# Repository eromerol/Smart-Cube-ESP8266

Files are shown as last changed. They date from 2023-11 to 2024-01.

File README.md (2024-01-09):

# Smart-Cube-ESP8266



DIY version of the **Aqara Magic Cube** with ESP8266.

This project is part of the Industrial Informatics course of the Electronics, Robotics and Mechatronics Engineering degree at the University of Malaga. 

The working group is formed by:
- Herrero Sánchez, María
- Romero Luque, Elisabeth María
- Serra González, Bartomeu

The project is inspired by: https://www.youtube.com/watch?v=N68S9l9z9i8
and following the tutorial of: https://naylampmechatronics.com/blog/45_tutorial-mpu6050-acelerometro-y-giroscopio.html

The descriptions of the elements used, together with their connection and description can be found at: 
* [Spanish version](https://github.com/eromerol/Smart-Cube-ESP8266/blob/main/Spanish%20Version/Montaje.md)
* [English version](https://github.com/eromerol/Smart-Cube-ESP8266/blob/main/English%20Version/Assembly.md)

The process of programming and commissioning of the cube can be found at: (insert link)

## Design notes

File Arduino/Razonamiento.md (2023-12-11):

# Desarrollo del '*programa_definitivo.ino*'

En este documento se detalla el funcionamiento del programa de Arduino.

Son necesarias las **librerías**:
  - Wire.h
  - MPU6050.h
  - I2Cdev.h

## SetUp

El SetUp tiene la forma:
<p align="center">


Donde se inicializa el sensor MPU6050 y se asigna el pin 16 (Vibration_signal) del sensor de vibración como entrada.

## Loop

Una vez dentro del bucle principal, obtenemos las lecturas de la rotación y de la aceleración:
<p align="center">


Y se le asignan a las variables creadas previamente:

<p align="center">


**NOTA:** Si vamos al [repositorio de la biblioteca MPU6050](https://github.com/ElectronicCats/mpu6050), dentro de 'src' encontramos la deifinición de los procedimientos en la carpeta MPU6050.cpp:

- **getRotation**
<p align="center">


- **getAcceleration**
<p align="center">


Donde se lee que las lecturas son de tipo entero de 16 bits y están en formato complemento a 2, por lo que después se les hace la conversión al sistema internacional.

**NOTA:** los rangos con los que está configurado el MPU6050 pueden ser 2g/4g/8g/16g para el acelerómetro y 250/500/1000/2000(°/s) para el giroscopio. Trabajaremos con los rangos por defecto (2g y 250°/s). La resolución de las lecturas es de 16 bits, por lo que el rango de lectura es de -32768 a 32767.

Sabiendo estos datos, la conversión para la lectura del giroscópio y la del acelerómetro queda como se muestra:

<p align="center">


## Cálculos de las rotaciones y las aceleraciones

Para calcular el ángulo actual necesitamos integrar la velocidad y conocer el ángulo incial. Esto lo hacemos usando la siguiente formula:

<p align="center">




Por lo que se declara: *(no sé por qué lo divide por 131)*

<p align="center">


---

Se calcula la **inclinación en cada eje** con la siguiente conversión.
La única fuerza que actúa sobre el sensor es la fuerza de la **gravedad**, por lo que los valores que obtenemos en las componentes del acelerómetro corresponden a la gravedad.

<p align="center">


De donde se puede deducir:

<p align="center">


Obteniendo los ángulos de inclinación:

<p align="center">


[EJEMPLO GET TEMPERATURE](https://www.i2cdevlib.com/forums/topic/612-why-the-3653-degree-offset-to-get-temperature/)
https://www.i2cdevlib.com/forums/topic/612-why-the-3653-degree-offset-to-get-temperature/

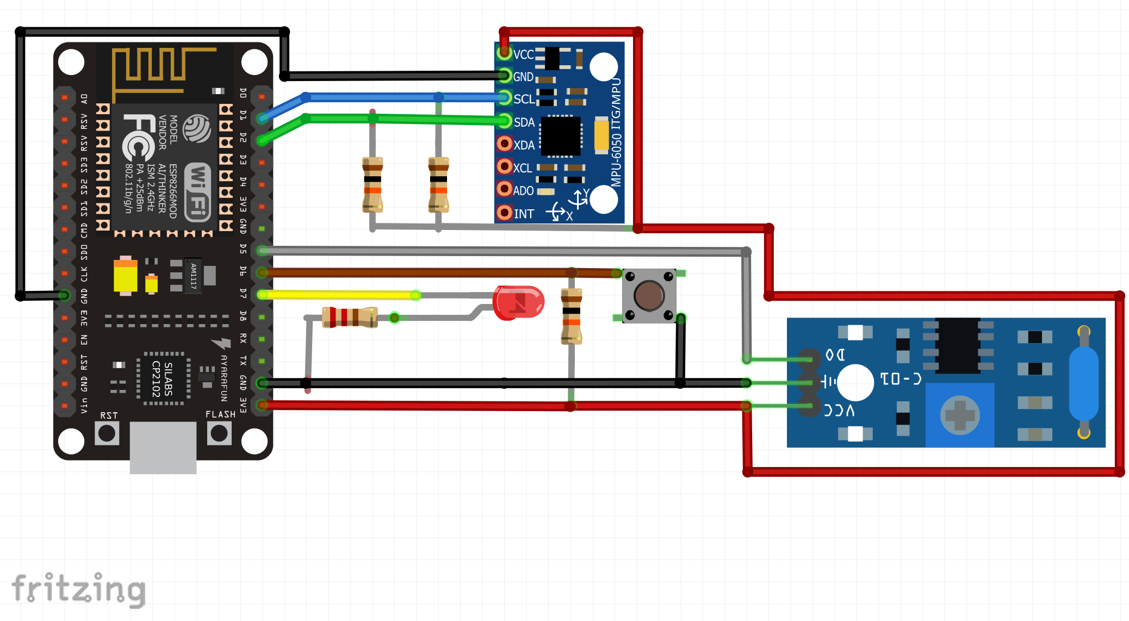
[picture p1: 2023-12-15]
Fritzing/Completo.png

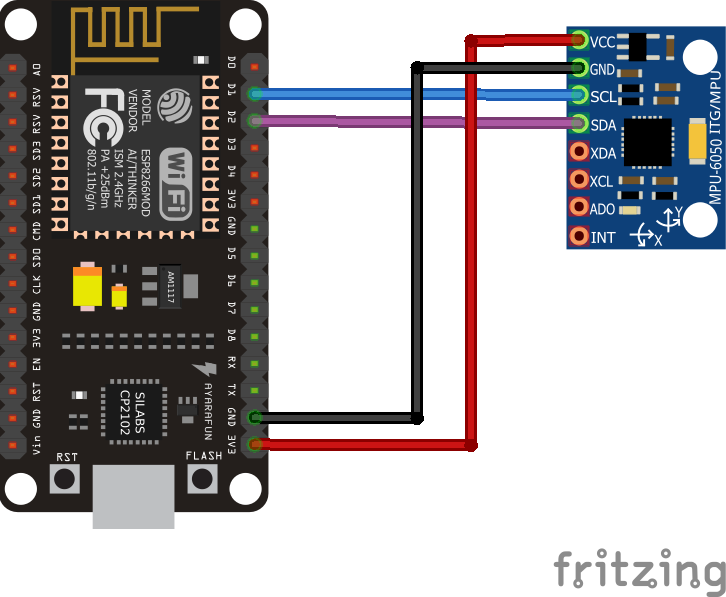
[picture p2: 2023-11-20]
Fritzing/conexion_esp8266_mpu6050.png

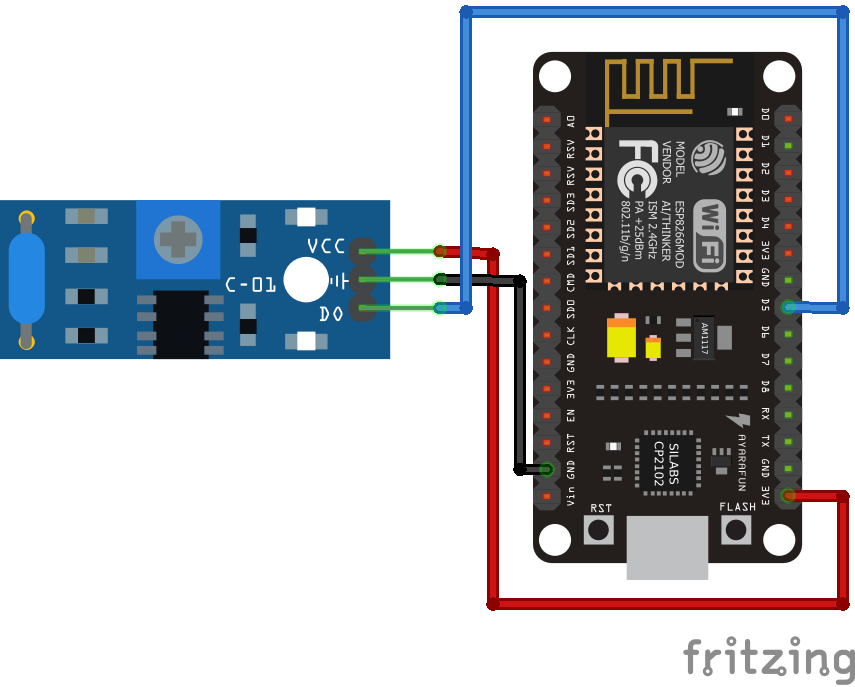
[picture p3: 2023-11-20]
Fritzing/conexion_esp8266_sw420.png

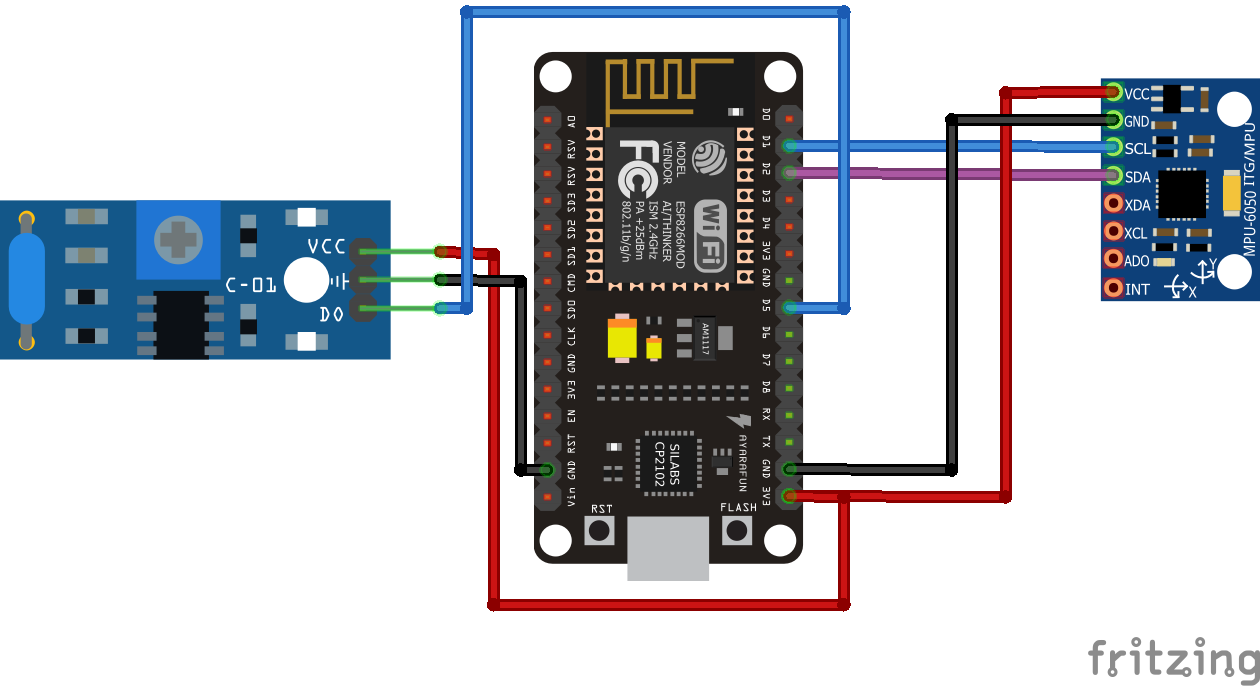
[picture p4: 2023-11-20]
Fritzing/conexion_esp8266_mpu6050_sw420.png

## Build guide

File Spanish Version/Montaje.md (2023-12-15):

El cubo de Aqara es un dispositivo inteligente que se puede utilizar para controlar la domótica de tu hogar. Tiene seis lados, cada uno con un sensor diferente que puede detectar movimientos, gestos y sonidos.

El cubo de Aqara se puede utilizar para controlar una amplia gama de dispositivos inteligentes, como luces, termostatos, puertas y ventanas. También se puede utilizar para crear automatizaciones, como encender las luces cuando entras en una habitación o apagar el termostato cuando sales de casa.

Nuestra versión hecha a mano se encargará de las mismas caraterísticas, y en este documento te enseñaremos como hacerlo:

🔌 COMPONENTES Y BATERÍAS
--------------------------



*   [Placa ESP8266](https://amzn.eu/d/aHI7mCz)
*   [3 ejes acelerómetro giroscopio MPU-6050](https://amzn.eu/d/f57rFlo) 
*   [Sensor de Vibración SW-420](https://amzn.eu/d/2fdRQOv) 
*   [Baterías y Cargador LiPo](https://amzn.eu/d/7FSwxyN)
*   [Placa de pruebas](https://amzn.eu/d/8O4BMnn)
*   [Cables Dupont](https://amzn.eu/d/6FpwoLk)
*   Pulsador
*   Resistencias

👨‍💻APPS
------

*   [Arduino IDE](https://www.arduino.cc/en/software)
*   [Fritzing](https://fritzing.org/)
*   [Node-RED](https://nodered.org/)
*   [Mongo DB](https://www.mongodb.com/es)
*   [Telegram](https://web.telegram.org/)

📚LIBRERÍAS
==========
*   [Adafruit_MPU6050](https://github.com/adafruit/Adafruit_MPU6050)
*   [MPU6050](https://github.com/jrowberg/i2cdevlib/tree/master/Arduino/MPU6050)
*   [PubSubClient](https://www.arduinolibraries.info/libraries/pub-sub-client)
*   [Wire](https://github.com/espressif/arduino-esp32/tree/master/libraries/Wire)
*   [WiFi](https://github.com/espressif/arduino-esp32/tree/master/libraries/WiFi)

DESCRIPCIÓN DEL HARDWARE
==============================
### MPU6050
El MPU-6050 es un sensor de movimiento de 6 ejes que combina un acelerómetro de 3 ejes y un giroscopio de 3 ejes en un solo chip. Es una opción popular para diversas aplicaciones, como robótica, drones y realidad virtual.

El MPU-6050 puede medir la aceleración y la velocidad angular en tres ejes: x, y y z. Estos datos se van a utilizar para seguir el movimiento de un objeto, como la posición, orientación o rotación de nuestro cubo mágico.

El esquema de conexión de este dispositivo con la placa ESP8266, junto con el pinout del componente, se puede ver en las siguientes imágenes:

<p align="center">


<p align="center">


Info vía: [Link1](http://www.sinaptec.alomar.com.ar/2017/10/tutorial-23-esp8266-obtener-inclinacion.html)
          [Link2](https://randomnerdtutorials.com/esp8266-nodemcu-mpu-6050-accelerometer-gyroscope-arduino/)

### SW-420

El SW-420 es un sensor que detecta vibraciones a partir de un umbral que puedes ajustar con el potenciómetro incluido. El módulo se basa en el sensor SW-420 y un comparador LM393 que produce una señal TTL cuando se activa.

El sensor de vibración de movimiento SW-420 es un sensor sencillo que utiliza un único pin de datos para detectar el movimiento. Además, el potenciómetro integrado proporciona una forma sencilla de ajustar el nivel de movimiento necesario para activar el pin digital.

No se necesitan librerías específicas para el ESP8266, ya que sólo utiliza el pin digital. Sin embargo, es importante asegurarse de conectar el pin VCC a la línea de 3,3 voltios. Esto se debe a que este es el voltaje máximo aceptado por los pines digitales.

El diagrama de conexión de este dispositivo con la placa ESP8266, junto con el pinout del componente, se puede ver en las siguientes imágenes:

<p align="center">


<p align="center">


Info vía: [Link1](https://chewett.co.uk/blog/1849/using-the-sw-420-motion-vibration-sensor-with-a-wemos-d1-mini-esp8266/)

### ESQUEMÁTICO COMPLETO

Para el desarrollo completo del cubo, se han añadido un **botón de presencia** (pulsador) y un **LED**. El esquemático completo, incluyendo los dos componentes descritos anteriormente, el pulsador, el LED y la placa, sería el siguiente:
<p align="center">


**NOTA:** para la comunicación I2C se han añadido las resistencias de Pull-Up en las líneas SCL y SDA.

Esta imagen, al igual que los esquemáticos anteriores, está realizada con la aplicación fritzing. Los archivos de los componentes se encuentran en la siguiente carpeta: [Fritzing](https://github.com/eromerol/Smart-Cube-ESP8266/tree/main/Fritzing)

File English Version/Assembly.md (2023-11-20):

The Aqara Cube is a smart device that can be used to control your home. It has six sides, each with a different sensor that can detect motion, gestures, and sounds.

The Aqara Cube can be used to control a wide range of smart devices, such as lights, thermostats, doors, and windows. It can also be used to create automations, such as turning on the lights when you enter a room or turning off the thermostat when you leave home.

Our handmade version will take care of the same features and in this document we will show you how to do it:

🔌 COMPONENTS AND SUPPLIES
--------------------------



*   [ESP8266 Board](https://amzn.eu/d/aHI7mCz)
*   [3 Axis Accelerometer Gyroscope MPU-6050](https://amzn.eu/d/f57rFlo) 
*   [Vibration Sensor SW-420](https://amzn.eu/d/2fdRQOv) 
*   [5 LiPo Batteries And Charger](https://amzn.eu/d/7FSwxyN)
*   [Breadboard](https://amzn.eu/d/8O4BMnn)
*   [Jumper Wires](https://amzn.eu/d/6FpwoLk)

👨‍💻APPS
------

*   [Arduino IDE](https://www.arduino.cc/en/software)
*   [Fritzing](https://fritzing.org/)
*   [Node-RED](https://nodered.org/)
*   [Mongo DB](https://www.mongodb.com/es)
*   [Telegram](https://web.telegram.org/)

📚Libraries
=====
*   [Adafruit_MPU6050](https://github.com/adafruit/Adafruit_MPU6050)
*   [Adafruit_Sensor](https://github.com/adafruit/Adafruit_Sensor)
*   [PubSubClient](https://www.arduinolibraries.info/libraries/pub-sub-client)
*   [Wire](https://github.com/espressif/arduino-esp32/tree/master/libraries/Wire)
*   [WiFi](https://github.com/espressif/arduino-esp32/tree/master/libraries/WiFi)

COMPONENTS DESCRIPTION
==============================
### MPU6050

The MPU-6050 is a 6-axis motion sensor that combines a 3-axis accelerometer and a 3-axis gyroscope in a single chip. It is a popular choice for a variety of applications, including robotics, drones, and virtual reality.

The MPU-6050 can measure acceleration and angular velocity in three axes: x, y, and z. This data is going to be used to track the movement of an object, such as the position, orientation, or rotation of our magic cube.

The connection diagram of this device with the ESP8266 board, together with the pinout of the component, can be seen in the following images:



conexion_esp8266_mpu6050

Info via: [Link1](http://www.sinaptec.alomar.com.ar/2017/10/tutorial-23-esp8266-obtener-inclinacion.html)
          [Link2](https://randomnerdtutorials.com/esp8266-nodemcu-mpu-6050-accelerometer-gyroscope-arduino/)

### SW-420

The SW-420 is a sensor that detects vibrations from a threshold that you can set with the included potentiometer. The module is based on the SW-420 sensor and an LM393 comparator producing a TTL signal when activated.

The SW-420 motion vibration sensor is a simple sensor that uses a single data pin to detect motion. In addition to this, the onboard potentiometer provides a simple way to adjust the level of motion needed to trigger the digital pin.

No ESP8266 specific libraries are required as this only uses the single digital pin. However it is important to ensure you connect the VCC pin to the 3.3 volts line. This is because this is the maximum voltage accepted by the digital pins.

The connection diagram of this device with the ESP8266 board, together with the pinout of the component, can be seen in the following images:



conexion_esp8266_sw420

Info via: [Link1](https://chewett.co.uk/blog/1849/using-the-sw-420-motion-vibration-sensor-with-a-wemos-d1-mini-esp8266/)

### SCHEMATIC DESIGN

The complete schematic design, including both components described above together with the board would be as follows:

conexion_esp8266_mpu6050_sw420

This image, like the previous schematics, is made with the fritzing application. The component files can be found in the following folder: [Fritzing](https://github.com/eromerol/Smart-Cube-ESP8266/tree/main/Fritzing)

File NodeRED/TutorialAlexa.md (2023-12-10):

# Control mediante dispositivo Alexa

## Configuración de nodos Alexa en Node-RED

### Instalar App
NOTA: Para hacer los pasos no es necesario tener un Alexa.
- Descargar la app Amazon Alexa y seguir los pasos para su configuración.
- Una vez la app esté configurada, le damos a Más -> Skills y juegos.
- Descargamos Spotify y Node-RED Smart Home Control y autorizamos el uso de ambas.
  
----------------------------------------------------------- HECHO ---------------------------------------------------------------

### Creamos los dispositivos a utilizar en Node-RED
- Nos vamos al siguiente enlace: https://red.cb-net.co.uk/
- Creamos una cuenta e iniciamos sesión.
- En https://red.cb-net.co.uk/devices añadimos los dispositivos necesarios junto a su descripción y la habitación en la que están.
- Estos dispositivos, una vez creados, deberían de aparecer en al app de Alexa, en el apartado de Dispositivos.
  
----------------------------------------------------------- HECHO ---------------------------------------------------------------

He creado los dispositivos del ejemplo: **sensor de temperatura** y **lámpara**.

<p align="center">


### Configuración en Node-RED
- Instalamos el paquete node-red-contrib-alexa-smart-home en Manege-Palette.
- Para poder usar los nodos necesitamos crear un nuevo autor, introduciendo los datos de la cuenta de https://red.cb-net.co.uk/
- Para añadir los dispositivos que poseemos en la app de Alexa usamos el nodo: alexa-smart-home-v3-state.
- Para añadir el propio Alexa usamos el nodo: alexa-smart-home-v3.

<p align="center">


DATOS:
  - **user: mariaherrresa**
  - **password: Herresa9.hola**

----------------------------------------------------------- HECHO ---------------------------------------------------------------

---

## Desarrollo de nuestro proyecto

Se crea un nuevo dispositivo llamado **termostato**.

<p align="center">


Se añade al flujo, junto con los dispositivos ya proporcionados por el profesor:

<p align="center">


Y creamos una función para interpretar las órdenes para el termostato:

<p align="center">


La función recoge el mensaje cuando la orden es de [ajustar la temperatura](https://docs.cb-net.co.uk/en/development/node-outputs.html) del termostato y transmite el payload. Como se indica, msg.payload = 1 significa incrementar en 1ºC la temperatura, y -1, disminuirla 1ºC.

NOTA: HAY UNA ORDEN DE CAMBIAR DE CANAL

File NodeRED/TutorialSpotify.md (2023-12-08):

# Cómo configurar el nodo de Spotify

## Crear cuenta de Autor
- Entramos en Spotify for Developers e iniciamos sesión con nuestra cuenta premium
- Seleccionamos en nuestro perfil la opción Dashboard y creamos una app. En la opcción de qué clase de API planeas usar seleccionamos WebAPI


- Una vez creada, seleccionamos Dashboard -> Nuestra app -> Settings, y copiamos el client_ID y el secret code que nos proporciona
- Client_ID: 48a4613cfba545758b6af8b453cb8690
- Client secret: 0e2977d09b8643ac90f61da8637c9d10
- En cuanto al URI que nos piden, como estamos corriendo Node-RED en el localhost, este debería de ser: http://localhost:1880/spotify-credentials/auth/callback

## Configuración de cuenta en Node-RED
Ahora que hemos creado nuestra app, añadimos nuestra cuenta de autor. 

Para ello añadimos un nodo Spotify y en credenciales seleccionamos Add new spotify auth..., en este nodo solo se debe añadir el Client ID y el client secret mencionados anteriormente junto a los Scopes necesarios, que en nuestro caso los siguientes: 
ugc-image-upload
user-read-playback-state
user-modify-playback-state
user-read-currently-playing
app-remote-control
streaming
playlist-read-collaborative
playlist-modify-private
playlist-modify-public

Una vez añadido todo esto se presiona Authentification y nos redirige a la URI de la app que acabamos de crear para aceptar que nuestra cuenta de spotify se conecte con ella:


Al aceptar, spotify nos ha autorizado y nos debe de aparecer un mensaje como el siguiente y habríamos termiando de configurar el nodo (dependiendo del API que seleccionemos alomejor nos pide más información, pero en los APIs de este proyecto no es necesario)


## Bibliografía
[Repositorio GitHub creador del nodo Spotify](https://github.com/pckhib/node-red-contrib-spotify)
[Documentación Spotify Web API](https://developer.spotify.com/documentation/web-api/tutorials/getting-started)

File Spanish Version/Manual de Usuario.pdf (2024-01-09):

Memoria Proyecto IoT | Grupo 7 | Informática Industrial

### 4. Manual de usuario

El objetivo de este manual es proporcionar instrucciones detalladas sobre el uso del Hardware y Software del proyecto e incluye la explicación de la configuración y movimientos del cubo, el proceso de instalación y configuración de Alexa, la manipulación de la herramienta desde el Dashboard de Node-RED y la instalación y uso del bot de
Telegram. | Con | todos | estos | puntos | se | pretende | que | cualquier | persona,
independientemente de sus conocimientos en el campo de la ingeniería, pueda hacer uso del proyecto.

### 4.1. Movimientos Cubo

Como se ha mencionado en el apartado 1, el Cubo de Aqara adopta la forma de un cubo con seis caras en cuyo interior se encuentran sensores de detección de movimiento y de vibración, junto con un botón adicional para confirmar, registrar y reconocer distintos tipos de movimientos. Las acciones que se asocian a cada cara incluyen:

- Un click del botón abre el dispositivo Cerradura.

Ilustración 70. Monitor Serie cerradura abierta.

- Doble click del botón cierra el dispositivo Cerradura.

Ilustración 71. Monitor Serie cerradura cerrada.

- Triple click del botón aumenta el valor el dispositivo Cortina en un 20 % con respecto a su valor anterior.

Ilustración 72. Monitor Serie cortina elevada.

- Mantener presionado el botón más de 1,5 s habilita el reconocimiento de variaciones en los ejes X, Y, Z:
- El giro en el eje X controla el volumen del dispositivo Altavoz. Un giro en el sentido negativo del eje hace que disminuya el volumen y en el sentido positivo, aumenta.

Ilustración 73. Monitor Serie volumen aumentado.

Ilustración 74. Monitor Serie volumen disminuido.

- El giro en el eje Y modifica la temperatura del dispositivo Termostato. Un giro en el sentido negativo del eje hace que disminuya en un grado la temperatura y en el sentido positivo, que aumente.

Ilustración 75. Monitor Serie valor termostato disminuido.

Ilustración 76. Monitor Serie valor termostato aumentado.

- El giro en el eje Z controla la intensidad de brillo del dispositivo Lámpara. Un giro en el sentido negativo hace que disminuya la intensidad y en el eje positivo, que aumente. El ángulo en el que se gira el cubo es el porcentaje en el cual se aumenta o disminuye el brillo del dispositivo, es decir, para alcanzar un 100% de intensidad se debe girar 180º (media vuelta).

Ilustración 77. Monitor Serie porcentaje lámpara disminuido.

Ilustración 78. Monitor Serie porcentaje lámpara aumentado.

- La sacudida del dispositivo hace que se encienda o apague el altavoz, depende del estado anterior del mismo.

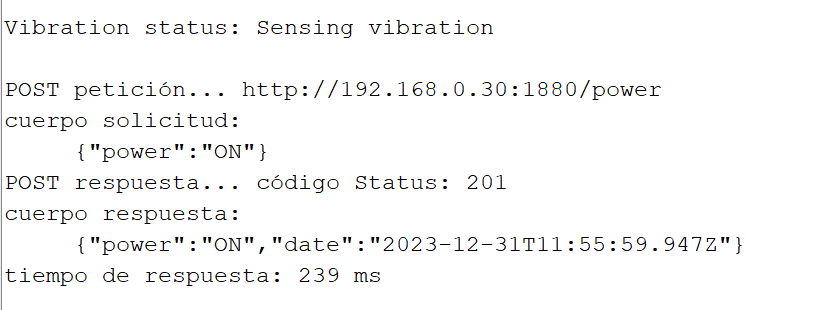
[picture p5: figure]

Ilustración 79. Monitor Serie Altavoz encendido.

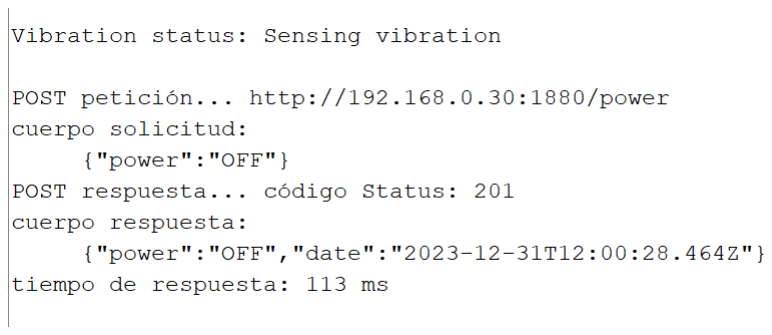
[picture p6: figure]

Ilustración 80. Monitor Serie Altavoz apagado.

### 4.2. Amazon Alexa App

A través de la aplicación Amazon Alexa, los usuarios pueden agregar, gestionar y controlar dispositivos inteligentes fácilmente, los cuales formen parte de su ecosistema doméstico conectado.

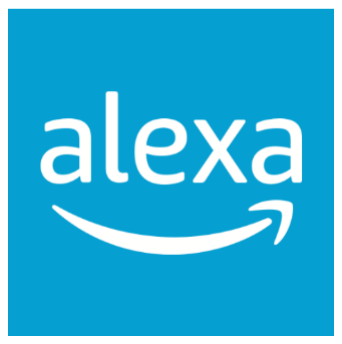
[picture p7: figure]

Ilustración 81. Logo App Alexa.

Los dispositivos utilizados en este proyecto no existen físicamente, sino que se han añadido a través de Skills. Las Skills son aplicaciones o funcionalidades adicionales que pueden ser agregadas a los dispositivos habilitados en Alexa. Para agregar una Skill, los usuarios pueden acceder a la aplicación Alexa, dirigirse a la sección de Skills y juegos, buscar la Skill deseada y habilitarla. En este caso, la Skill usada es “Node-RED Smart Home Control” y para poder configurarla se necesita crear los dispositivos que posteriormente se van a usar.

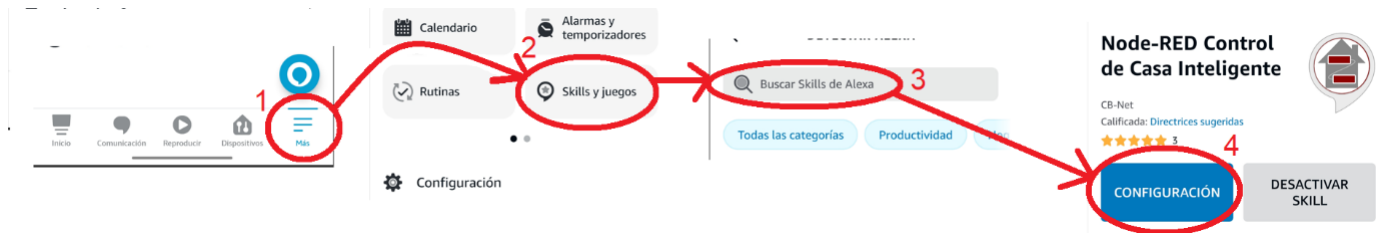
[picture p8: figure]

Ilustración 82. Aplicación Alexa. Añadir Skills.

Para ello, iniciamos sesión o nos registramos en el enlace del desarrollador de esta Skills https://red.cb-net.co.uk/ y añadimos o modificamos los dispositivos a nuestro gusto. Al añadir un dispositivo, se le tiene que poner nombre, descripción, seleccionar qué tipo de dispositivo va a ser y las funciones que va a tener disponibles.

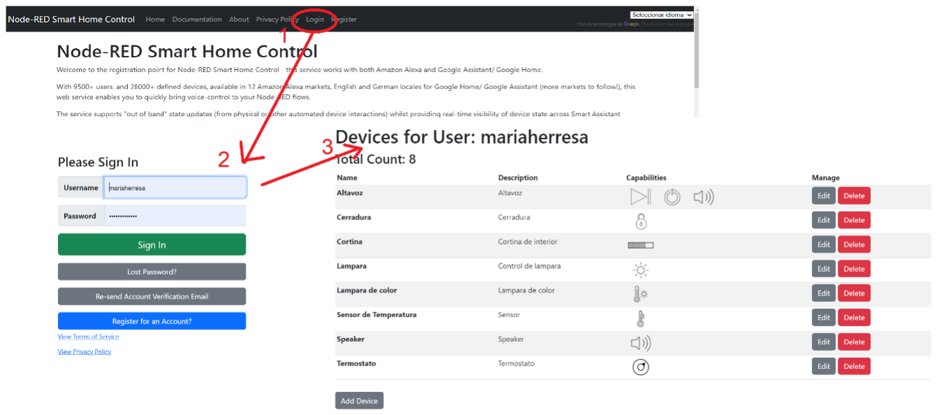
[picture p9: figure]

Ilustración 83. Añadir y gestionar dispositivos.

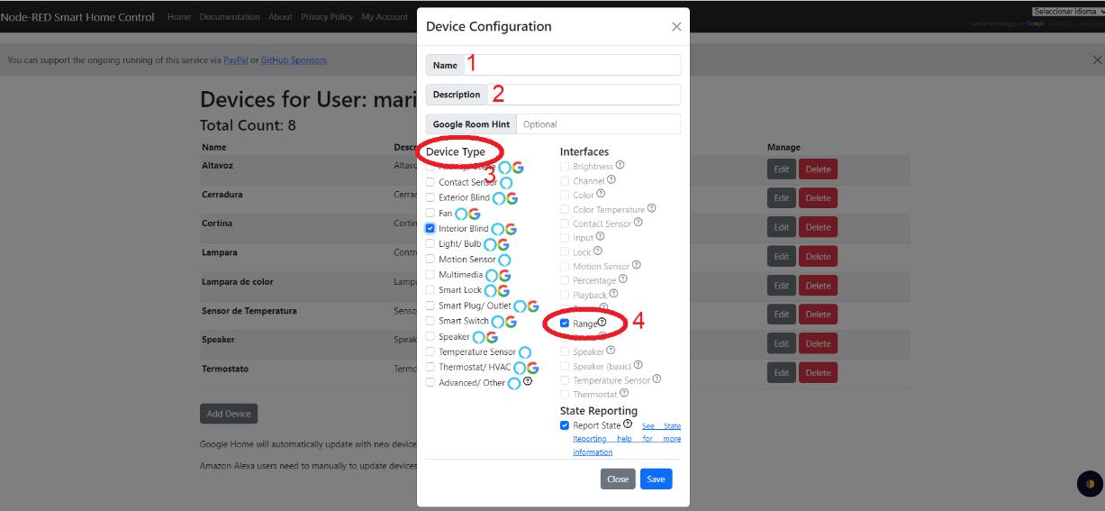
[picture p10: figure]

Ilustración 84. Configurar dispositivos.

En la configuración de esta Skills desde la aplicación de Alexa, se deben de introducir los datos de la cuenta anteriormente creada y de esta forma, una vez vinculada, directamente Alexa buscará y reconocerá los dispositivos creados para que puedan ser añadidos y controlados mediante comandos de voz. Una vez terminado esto, los dispositivos están listos para ser utilizados.

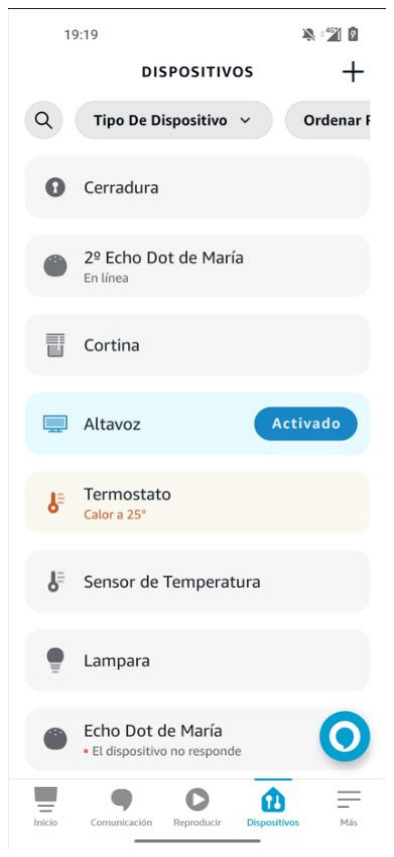
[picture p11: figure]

Ilustración 85. Aplicación Alexa. Dispositivos disponibles.

### 4.3. Dashboard

El Dashboard es una interfaz web en la que se podrá visualizar toda la información de los dispositivos, así como controlarlos en tiempo real mediante el uso de botones y “sliders”. El Dashboard consta de cinco secciones:

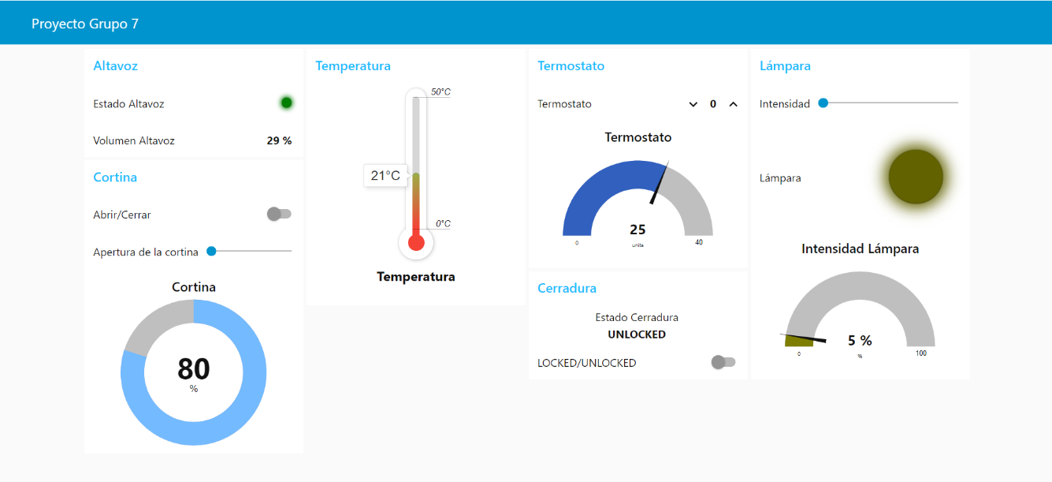
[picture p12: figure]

Ilustración 86. Vista general Dashboard.

A continuación, se explicará la funcionalidad de cada una de las secciones que componen la interfaz web.

- En la sección “Altavoz” se puede ver el estado del altavoz a través de un LED, y el volumen del mismo mediante texto. Si se encuentra apagado, el LED estará en rojo y si está encendido, el LED estará en verde. A medida que cambiemos el volumen del altavoz, el nuevo porcentaje sobre 100 aparecerá reflejado en “Volumen Altavoz”.

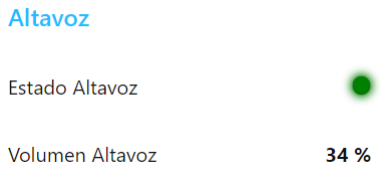
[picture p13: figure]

Ilustración 87. Sección Altavoz encendido.

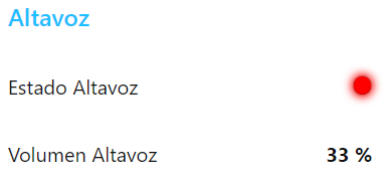
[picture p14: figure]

Ilustración 88. Sección Altavoz apagado y volumen modificado.

- En la sección “Temperatura” se indica, a través de un termómetro en grados centígrados, la temperatura que nos proporciona el sensor MPU-6050.

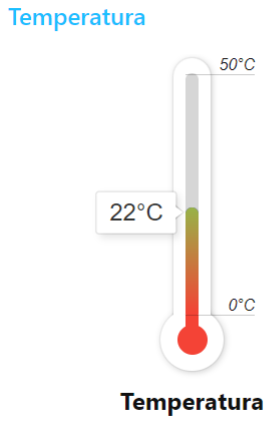
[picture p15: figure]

Ilustración 89. Sección Temperatura.

- En la sección “Termostato” se puede observar un indicador de la temperatura del mismo y un nodo numérico para que el usuario configure la temperatura que desee presionando las flechas arriba y abajo.

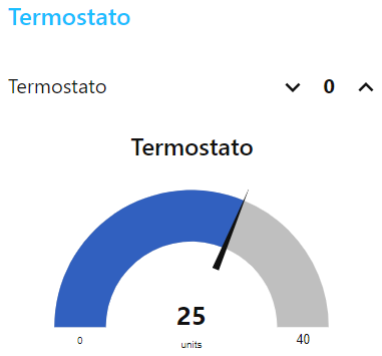
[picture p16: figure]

Ilustración 90. Sección Termostato con valores recibidos.

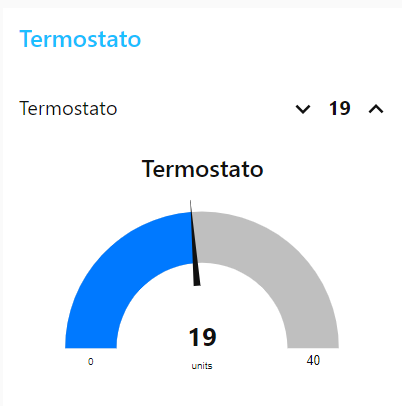
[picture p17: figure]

Ilustración 91. Sección Termostato modificado por el usuario.

- La sección “Lámpara” presenta un indicador de 0 a 100 con la intensidad de brillo del dispositivo, junto a un LED que simula cómo se vería la lámpara con la intensidad actual y un “slider” de 0 a 100 para que el usuario modifique el brillo según considere necesario.

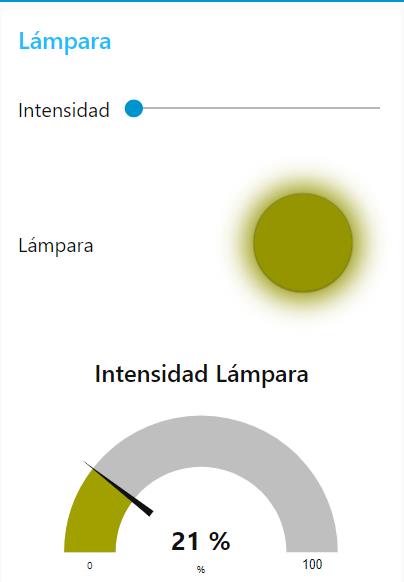
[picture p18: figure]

Ilustración 92. Sección Lámpara con valores recibidos.

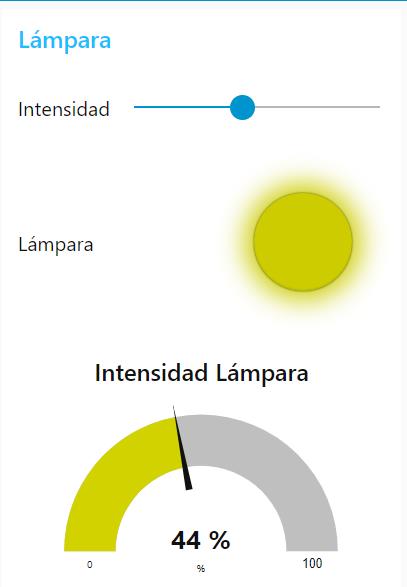
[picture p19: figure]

Ilustración 93. Sección Lámpara modificada por el usuario.

- En la sección “Cortina” se puede ver y controlar el estado de la misma. Se incluye un “switch” de 0 ó 1, donde 0 indica que la persiana está totalmente bajada (0 %) y 1, totalmente subida (100 %), junto a un slider de 0 a 100 por si el usuario desea situar el dispositivo en cualquiera de sus otras posiciones. Además, a través del indicador tipo Donut podemos observar de forma gráfica el estado actual.

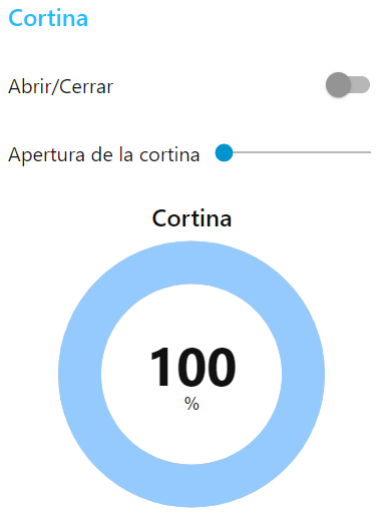
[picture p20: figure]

Ilustración 94. Sección Cortina con valores recibidos.

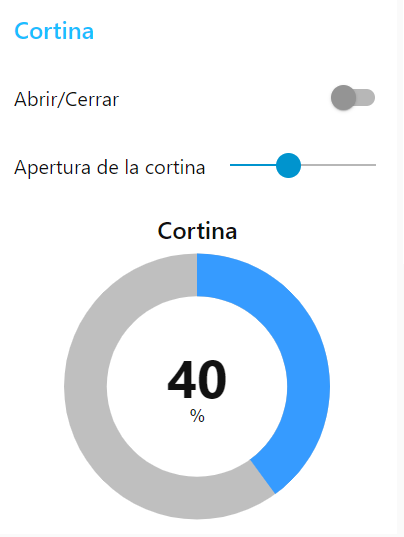
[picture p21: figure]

Ilustración 95. Sección Cortina modificada por el usuario con slider.

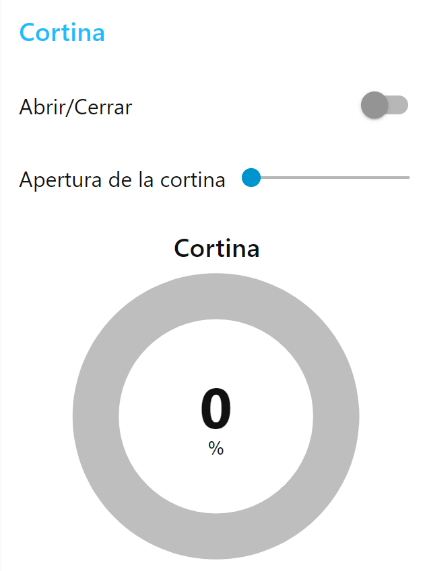
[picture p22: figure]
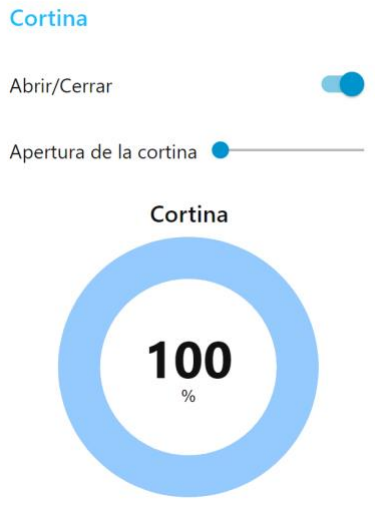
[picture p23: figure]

Ilustración 96. Sección Cortina modificada por el usuario con switch.

- En la sección “Cerradura” podemos ver el estado del dispositivo en formato de texto, donde “UNLOCKED” significa que está abierta y “LOCKED”, cerrada.

Ilustración 97. Sección estado de la Cerradura.

### 4.4. Telegram

El bot de Telegram “infind_aqaracube_bot” está diseñado para proporcionar información detallada sobre los dispositivos del hogar conectados. Para poder acceder a él, basta con iniciar sesión o registrarse en la aplicación de Telegram y buscar, en la barra “Search”, el nombre completo del bot. Una vez seleccionado, se presiona la opción “UNIRME” y ya estaremos dentro.

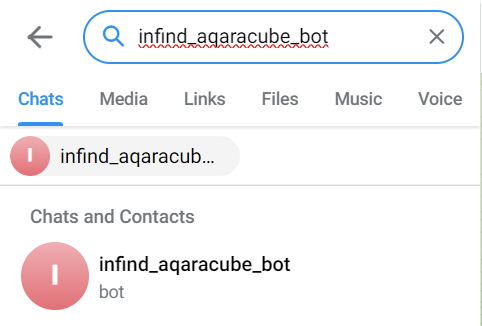
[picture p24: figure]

Ilustración 98. Búsqueda del bot en Telegram.

En primer lugar, se recomienda que el usuario acceda a la lista de comandos disponibles a los que responde el bot. Para ello, se debe escribir el comando “/start” en la ventana de chat del bot, obteniéndose un mensaje de bienvenida con las diferentes opciones de consulta.

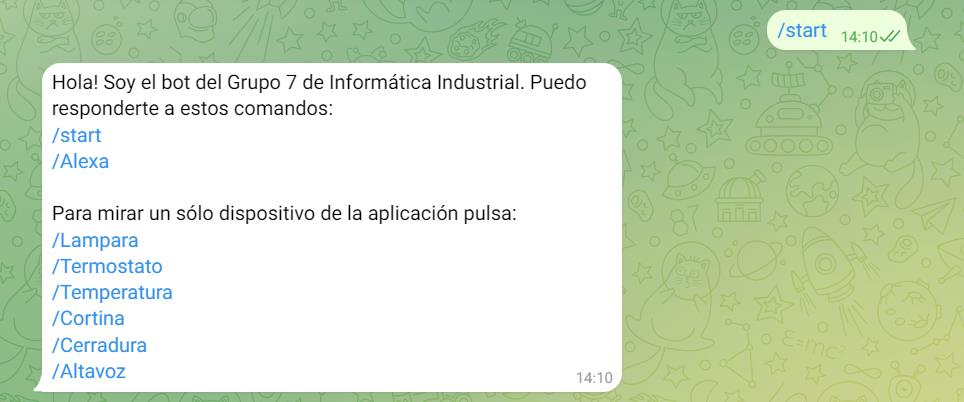
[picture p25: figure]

Ilustración 99. Mensaje de bienvenida.

A través de estas consultas, los usuarios pueden solicitar datos específicos de cada dispositivo de forma individual: el nivel de brillo de la lámpara, el estado y volumen del altavoz, la temperatura del termostato, el estado de la cortina, la temperatura actual o el estado de la cerradura.

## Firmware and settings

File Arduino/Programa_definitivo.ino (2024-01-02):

#include <Wire.h>
#include <MPU6050.h> //Biblioteca sensor
#include <I2Cdev.h>  //Biblioteca comunicacion I2C
#include "Button2.h" //Biblioteca pulsaciones
#include <ArduinoJson.h> //Biblioteca JSON
#include <PubSubClient.h> //Biblioteca MQTT
#include <ESP8266WiFi.h> // Biblioteca WIFI ESP8266
#include <ESP8266HTTPClient.h> //Biblioteca HTTP ESP8266
#include <string>
#include <iostream>
#include <sstream>

/////////////////////////////////////////////////////////////////

#define BUTTON_PIN  12
#define MPU 0x68

/////////////////////////////////////////////////////////////////

Button2 button;
MPU6050 mpu;

// Inicializamos el cliente WiFi
WiFiClient espClient;
PubSubClient mqtt_client(espClient);

/////////////////////////////////////////////////////////////////
// Inicializamos el cliente HTTPS

HTTPClient https;

//#define __HTTPS__
#ifdef __HTTPS__
  #include <WiFiClientSecure.h>
  WiFiClientSecure ClienteWiFi;
  const String URL_BASE = "https://iot.ac.uma.es:1880";
  // huella digital SHA-1 del servidor iot.ac.uma.es (vencimiento enero 2024)
  const char* fingerprint = "DE:3C:76:79:45:D8:F0:13:9F:22:A5:42:97:0B:F6:56:4E:E6:B8:FD";
#else
  #include <WiFiClient.h>
  WiFiClient ClienteWiFi;
  const String URL_BASE = "http://192.168.0.32:1880";
#endif


/////////////////////////////////////////////////////////////////

// Definimos pines generales
int pinled = 13;
int led = 2;
int Vibration_signal = 14;

// Declaramos variables
int brillo = 0;
int lamp = 0;
String cerradura = "LOCKED";
float temperatura;
int Cortina_prev = 40;
int Cortina;
int termostato;
int termostato_prev = 25;
int volumen;
int volumen_prev = 30;
int contador = 1;
bool subir = true;
int codigoStatus;
String respuesta = "";

// Definimos datos de la red WiFi
const String ssid = "infind";
const String password = "1518wifi";

// Definimos el servidor MQTT
const String mqttServer = "iot.ac.uma.es";
const String mqttUser = "II7";
const String mqttPassword = "hbum58oh";

// Definimos String
String ID_PLACA;
String topic_Alexa;

// Variables del acelerometro
int16_t ax, ay, az; 

// Variables del giroscopio
int16_t gx, gy, gz;
int16_t temp_raw;

long tiempo_prev, dt;
float girosc_ang_x, girosc_ang_y, girosc_ang_z;
float girosc_ang_x_prev, girosc_ang_y_prev, girosc_ang_z_prev;

float umbral = 70.0; // Umbral para detección de giro
//-------------------------------------------------------
//                     CONECTA WIFI
//-------------------------------------------------------
void conecta_wifi() {
  Serial.println("Conectando a " + ssid);
 
  WiFi.mode(WIFI_STA);
  WiFi.begin(ssid, password);

  while (WiFi.status() != WL_CONNECTED) {
    delay(200);
    Serial.print(".");
  }
  Serial.println();
  Serial.println("WiFi conectado, direccion IP: " + WiFi.localIP().toString());
}

//-------------------------------------------------------
//                     CONECTA MQTT
//-------------------------------------------------------
void conecta_mqtt() {
  // Bucle hasta que estemos reconectados

  while (!mqtt_client.connected()) {
    Serial.println("Conectando al servidor MQTT...");

    // Intentamos conectarnos
    if (mqtt_client.connect(ID_PLACA.c_str(), mqttUser.c_str(), mqttPassword.c_str())) {
      Serial.println("Conectado a: " + mqttServer);

    } else {
       Serial.println("ERROR:"+ String(mqtt_client.state()) +" reintento en 5s" );

      // Esperamos 5 segundos antes de volver a intentarlo
      delay(5000);
    }
  }
}

//-----------------------------------------------------------
//                Peticiones HTTP
//-----------------------------------------------------------
int http_GET(String URL, String* respuesta)
{
  return peticion_HTTP("GET", URL, "", respuesta);
}
//-----------------------------------------------------------
int http_POST(String URL, String body, String* respuesta)
{
  return peticion_HTTP("POST", URL, body, respuesta);
}
//-----------------------------------------------------------
int peticion_HTTP (String metodo, String URL, String body, String* respuesta)
{
  int httpCode=-1;
  unsigned long start = millis();
  if (https.begin(ClienteWiFi, URL)) {  // HTTPS

      Serial.println(metodo +" petición... " + URL);
      // start connection and send HTTP header
      https.addHeader("Content-Type", "application/json");
      if(metodo=="GET" )  httpCode = https.GET();
      if(metodo=="POST"){ httpCode = https.POST(body);
        Serial.println("cuerpo solicitud: \n     "+ body);
      }
      // httpCode will be negative on error
      if (httpCode > 0) {
        Serial.println(metodo +" respuesta... código Status: "+ String(httpCode));

        // queremos la respuesta del servidor
        if (respuesta!=NULL) {
          *respuesta = https.getString();
          Serial.println("cuerpo respuesta: \n     "+ *respuesta);
        }
      } else {
        Serial.println(metodo +"... falló, error: "+ String(https.errorToString(httpCode).c_str()) );
      }

      https.end();
    } else {
      Serial.println("No se pudo conectar");
    }
    Serial.println("tiempo de respuesta: "+ String(millis()-start) +" ms\n");
    return httpCode;
}



//-------------------------------------------------------
//                      SETUP
//-------------------------------------------------------
void setup(void) {
  respuesta="";
  Serial.begin(115200);

  Wire.begin();
  Wire.beginTransmission(MPU);
  Wire.endTransmission(true);

  pinMode(pinled, OUTPUT);
  pinMode(Vibration_signal, INPUT); //Set pin as input

  mpu.initialize(); // Inicializamos el giroscopio

  // Deteccion de pulsacion del boton
  button.begin(BUTTON_PIN);
  button.setClickHandler(singleClick);
  button.setLongClickHandler(longClick);
  button.setDoubleClickHandler(doubleClick);
  button.setTripleClickHandler(tripleClick);
  //button.setLongClickHandler(longClickDetected);
  
  ID_PLACA = "ESP" + String(ESP.getChipId()); //Obtenemos el chipID

  // Creamos los topics
  topic_Alexa="II7/"+ ID_PLACA +"/Alexa"; //Publicar

  // Nos conectamos al WiFi
  conecta_wifi();

   // Inicializamos el servidor MQTT y nos conectamos
  mqtt_client.setServer(mqttServer.c_str(), 1883);
  mqtt_client.setBufferSize(512); // para poder enviar mensajes de hasta X bytes
  conecta_mqtt();

  #ifdef __HTTPS__
  ClienteWiFi.setFingerprint(fingerprint); // se comprobará el certificado del servidor
  //sslClienteWiFi.setInsecure(); // si no se quiere comprobar el certificado del servidor
  #endif
    
  if (mpu.testConnection()) Serial.println("Sensor iniciado correctamente");
  else Serial.println("Error al iniciar el sensor");
  
  Serial.println("MPU6050 Found!");

  // Calibramos el giroscopio
  mpu.CalibrateGyro(6);

  // Inicializamos el termostato
  termostato=termostato_prev;
  
  // Inicializamos el volumen
  volumen=volumen_prev;

  // Inicializamos la cortina
  Cortina=Cortina_prev;

  // Inicilizamos la temperatura
  temperatura=20;
  
  delay(100);

  tiempo_prev = millis();
  Serial.println("Fin setup");
}
//-------------------------------------------------------
//                      LOOP
//-------------------------------------------------------
void loop() {
  if (!mqtt_client.connected()) conecta_mqtt();
  
  mqtt_client.loop(); // esta llamada para que la librería recupere el control

  button.loop(); //Comprueba todo el tiempo el tipo de pulsación

}

//-------------------------------------------------------
//               FUNCIONES PULSACIONES
//-------------------------------------------------------
void singleClick(Button2& btn) {
  
  Serial.println("click\n");

  // Desbloqueamos la cerradura de casa 
  cerradura="UNLOCKED";
  Alexa();
}
//void longClickDetected(Button2& btn) {
//    Serial.println("long click detected");
//}
void longClick(Button2& btn) {

  Serial.println("long click\n");

  // Almacenamos el tiempo de pulsacion
  unsigned int time= btn.wasPressedFor();
  if (time>1500){ // Si es mayor a 1.5 Segundos, se llama al loop 2
    loop2();
  }
}
void doubleClick(Button2& btn) {

    Serial.println("double click\n");

    // Bloqueamos la cerradura de casa 
    cerradura="LOCKED";
    Alexa();
}
void tripleClick(Button2& btn) {
    Serial.println("triple click\n");
     
    if (Cortina==100){
      Cortina = Cortina_prev - 20;
      subir=false;
    } else if (Cortina==0) {
      Cortina = Cortina_prev + 20;
      subir=true;
    } else {
        if (subir==true){
        Cortina = Cortina_prev + 20;
      } else{
        Cortina = Cortina_prev - 20;
      }
    }
    Alexa();
    Cortina_prev=Cortina;
}
//-------------------------------------------------------
//               PUBLICACION ALEXA
//-------------------------------------------------------
void Alexa()
{
  // Construimos el objeto JSON para el topic 'Alexa'
  StaticJsonDocument<300> jsonDoc;
  jsonDoc["Lampara"] = lamp;
  jsonDoc["Volumen"] = volumen;
  jsonDoc["Temperatura"] = temperatura;
  jsonDoc["Termostato"] = termostato;
  jsonDoc["Cortina"] = Cortina;
  jsonDoc["Lock"] = cerradura;

  // Serializar el objeto JSON a una cadena
  String jsonPayload;
  serializeJson(jsonDoc, jsonPayload);

  // Publicar el JSON en el topic 'Alexa'
  mqtt_client.publish(topic_Alexa.c_str(), jsonPayload.c_str());
  Serial.println("\nTopic   : "+ topic_Alexa);
  Serial.println("Payload : "+ jsonPayload);
}
//-------------------------------------------------------
//               PULSACION LARGA
//-------------------------------------------------------
void loop2(){
  // Leer las aceleraciones y velocidades angulares, todas de tipo entero de 16 bits y en complemento a 2
  mpu.getAcceleration(&ax, &ay, &az);
  mpu.getRotation(&gx, &gy, &gz);

  // Conversion a sistema internacional
  float ax_m_s2 = ax * (9.81/16384.0);
  float ay_m_s2 = ay * (9.81/16384.0);
  float az_m_s2 = az * (9.81/16384.0);
  float gx_deg_s = gx * (250.0/32768.0);
  float gy_deg_s = gy * (250.0/32768.0);
  float gz_deg_s = gz * (250.0/32768.0);

  //Calcular los angulos de inclinacion:
  float accel_ang_x=atan(ax/sqrt(pow(ay,2) + pow(az,2)))*(180.0/3.14);
  float accel_ang_y=atan(ay/sqrt(pow(ax,2) + pow(az,2)))*(180.0/3.14);
  float accel_ang_z=atan(az/sqrt(pow(ax,2) + pow(ay,2)))*(180.0/3.14);

  // Necesitamos el incremento de tiempo
  dt = millis()-tiempo_prev;
  tiempo_prev=millis();
  
  // El nuevo angulo de rotacion es el incremento de tiempo por la velocidad angular (gx) + la rotacion anterior 
  girosc_ang_x = (gx/131)*dt/1000.0 + girosc_ang_x_prev;
  girosc_ang_y = (gy/131)*dt/1000.0 + girosc_ang_y_prev;
  girosc_ang_z = (gz/131)*dt/1000.0 + girosc_ang_z_prev;

  girosc_ang_x_prev=girosc_ang_x;
  girosc_ang_y_prev=girosc_ang_y;
  girosc_ang_z_prev=girosc_ang_z;

  // Limitamos que la lectura sea entre 0 y 180 (fmod devuelve el resto de dividir girosc_ang_z/180)
  float girx = fmod(girosc_ang_x,float(180));
  float giry = fmod(girosc_ang_y,float(180));
  float girz = fmod(girosc_ang_z,float(180));

  //Mostrar los angulos separadas por un [tab]
  Serial.print("Rotacion en X: ");
  Serial.print(girx); 
  Serial.print("\tRotacion en Y: ");
  Serial.print(giry);
  Serial.print("\tRotacion en Z: ");
  Serial.print(girz);
  
  // Registramos la temperatura y la convertimos a grados celsius
  temp_raw = mpu.getTemperature(); // Temperatura en formato int_16 y en complemento a 2
  temperatura = (temp_raw + 521)/340 + 35.0;

  // ---------- INTERPRETACION DE LAS LECTURAS ------------

  // ----------- ORDENES DESDE DASHBOARD ---------

  int codigoStatus = http_GET(URL_BASE+"/brillo", &respuesta);
  if (codigoStatus == 200) { // Si el código de estado HTTP es 200 (OK)
      // Interpretar la respuesta
      StaticJsonDocument<200> doc;
      DeserializationError error = deserializeJson(doc, respuesta);
      if (error) {
        Serial.println("Falló la deserialización del JSON");
      } else {
        // Extraer los valores de la respuesta
        lamp = doc["brillo"];
        Serial.println("Brillo desde dashboard: " + String(lamp));
        Alexa();
      }
    } else {
      Serial.println("Falló la petición GET, código de estado: " + String(codigoStatus));
    }

  // ------------ VIBRACIONES ---------------

  Serial.print("\nVibration status: ");
  bool Sensor_State = digitalRead(Vibration_signal);
  if (Sensor_State == true) {
    Serial.println("Sensing vibration\n");

    if (contador==1){
      String payload = "{\"power\":\"" + String("ON") + "\"}";

      codigoStatus = http_POST(URL_BASE+"/power", payload, &respuesta);

      contador = contador + 1;
      
    }else{
      String payload = "{\"power\":\"" + String("OFF") + "\"}";

      codigoStatus = http_POST(URL_BASE+"/power", payload, &respuesta);

      contador = 1; //Reseteamos el contador
    }
    
    delay(500);
  }
  else if(Sensor_State == false){
    Serial.println("No vibration\n");
    delay(500);

    // Si la rotación en el eje X supera el umbral establecido
    if (abs(accel_ang_x) >= umbral) {
      Serial.println("\n¡Giro en el eje X detectado! " +  String(girx) + "\t Musica");
      if(accel_ang_x>0){   // Pasa a la cancion siguiente
        if (volumen_prev<100){
          volumen = volumen_prev + 1;
        }
      } else if (accel_ang_x<0){   // Retrocede a la cancion anterior
        if (volumen_prev>0){
          volumen = volumen_prev - 1;
        }
      } 
      Alexa();
      volumen_prev=volumen;   
    }
    // Si la rotación en el eje Y supera el umbral establecido
    else if (abs(accel_ang_y) >= umbral) {
      Serial.println("\n¡Giro en el eje Y detectado! " + String(giry) + "\t Termostato");
      // Realiza alguna acción aquí (p. ej., encender un LED, enviar una señal, etc.)
      if(accel_ang_y<0){
        termostato = termostato_prev - 1;   // Decrementa un grado 
      }else if(accel_ang_y>0){
        termostato = termostato_prev + 1;    // Incrementa un grado
      }
      termostato_prev = termostato; // Lo almacenamos
      // Publicamos en Alexa
      Alexa();
    }
    // Si la rotación en el eje Z supera el umbral establecido
    else if (abs(girz) >= umbral) {
      Serial.println("\n¡Giro en el eje Z detectado!: " + String(girz) + "\t Lampara");
      // Limita la intensidad de la lampara de 0 a 100
      lamp = map(abs(girz), 0,180, 100,0);
      lamp = constrain(lamp,0,100);
      // Publicamos en Alexa
      Alexa();

      // Limita la intensidad del LED de 0 a 255
      brillo = map(lamp, 0,100, 255,0);
      brillo = constrain(brillo,0,255);
      analogWrite(pinled, brillo);   // Lo manda al LED
    }
      
  }

  delay(100);
}

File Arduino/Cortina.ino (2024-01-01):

#include <ArduinoJson.h> // Biblioteca JSON
#include <WiFi.h>        // Biblioteca WiFi ESP32
#include <PubSubClient.h> // Biblioteca MQTT
#include <Stepper.h>   // Biblioteca para motores paso a paso

// Inicializamos el cliente WiFi
WiFiClient espClient;
PubSubClient mqtt_client(espClient);


// Motor paso a paso
int pasosPorVuelta = 2048;
int porcentajeanterior = 0;
// ULN2003 Motor Driver Pins
#define IN1 19
#define IN2 18
#define IN3 5
#define IN4 17
Stepper myStepper(pasosPorVuelta, IN1, IN3, IN2, IN4);

// Topic Cortina
String topic_Alexa;

// Definimos datos de la red WiFi
const String ssid = "MOVISTAR_1AFF_INV";
const String password = "971867820";

// Definimos el servidor MQTT
const String mqttServer = "iot.ac.uma.es";
const String mqttUser = "II7";
const String mqttPassword = "hbum58oh";

// Definimos el ID_PLACA(MAC) DEL ESP32
uint64_t esp32ChipId = ESP.getEfuseMac();
String ID_PLACA = String(esp32ChipId, HEX);
//-------------------------------------------------------
//                     CONECTA WIFI
//-------------------------------------------------------
void conecta_wifi()
{
  Serial.println("Conectando a " + String(ssid));

  WiFi.begin(ssid, password);

  while (WiFi.status() != WL_CONNECTED)
  {
    delay(200);
    Serial.print(".");
  }
  Serial.println();
  Serial.println("WiFi conectado, dirección IP: " + WiFi.localIP().toString());
}

//-------------------------------------------------------
//                     CONECTA MQTT
//-------------------------------------------------------
void conecta_mqtt()
{
  // Bucle hasta que estemos reconectados
  while (!mqtt_client.connected())
  {
    Serial.println("Conectando al servidor MQTT...");

    // Intentamos conectarnos
    if (mqtt_client.connect(ID_PLACA.c_str(), mqttUser.c_str(), mqttPassword.c_str()))
    {
      Serial.println("Conectado a: " + String(mqttServer));
      mqtt_client.subscribe(topic_Alexa.c_str());
    }
    else
    {
      Serial.println("ERROR:" + String(mqtt_client.state()) + " reintento en 5s");

      // Esperamos 5 segundos antes de volver a intentarlo
      delay(5000);
    }
  }
}

//-----------------------------------------------------
void procesa_mensaje(char *topic, byte *payload, unsigned int length)
{
  String mensaje = String((char *)payload);
  Serial.println("Mensaje recibido [" + String(topic) + "] " + mensaje);

  // Verificamos el tema y actuamos en consecuencia
  if (String(topic) == topic_Alexa.c_str())
  {
    StaticJsonDocument<512> jsonDoc;
    DeserializationError error = deserializeJson(jsonDoc, mensaje);

    // Comprobar errores de deserialización
    if (error)
    {
      Serial.print("Error al deserializar JSON: ");
      Serial.println(error.c_str());
    }
    else
    {
      // Comprobar si el campo "Cortina" está presente
      if (jsonDoc.containsKey("Cortina"))
      {
        String estadoCortina = jsonDoc["Cortina"];
        int porcentaje = estadoCortina.toInt();
        // if (pocentaje < porcentajeanterior){
        //   for (int i = 0; i < porcentaje; i++)
        // myStepper.step(pasoPorVuelta);
        // } if else (pocentaje > porcentajeanterior){
        // myStepper.step(-pasoPorVuelta);
        // } else 
      
        if (porcentaje >= 0 && porcentaje <= 100)
        {
          Serial.println("Cortina: " + String(porcentaje) + "%");

          // Calcula la cantidad de pasos basándote en un rango de porcentaje
          int pasos = map(porcentaje, 0, 100,-pasosPorVuelta, pasosPorVuelta);
          int tiempo = map(abs(porcentajeanterior-porcentaje),0,100,0,20);
          porcentajeanterior = porcentaje;
          // Mueve el motor a la posición correspondiente al porcentaje recibi
          for (int i = 0; i < tiempo; i++){
           myStepper.step(pasos);
          }
        }
        else
        {
          Serial.println("Estado de la cortina desconocido: " + estadoCortina);
        }
      }
      else
      {
        Serial.println("Mensaje no contiene información sobre la cortina");
      }
    }
  }
}

void setup()
{
  Serial.begin(115200);
  Serial.println();
  Serial.println("Empieza setup...");
  myStepper.setSpeed(10);
  Serial.println("ID único del ESP32: " + ID_PLACA);
  topic_Alexa = "II7/ESP833252/Cortina";
  mqtt_client.setServer(mqttServer.c_str(), 1883);
  mqtt_client.setBufferSize(512); // para poder enviar mensajes de hasta X bytes
  mqtt_client.setCallback(procesa_mensaje);
  conecta_wifi();
  conecta_mqtt(); // Mover esta línea aquí
  Serial.println("Fin setup...");
}

void loop()
{
  if (!mqtt_client.connected())
  {
    conecta_mqtt();
  }

  mqtt_client.loop(); // Esta llamada permite que la librería recupere el control
}

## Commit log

2023-11-20 Rename MPU-6050 Board GY-521.fzpz to Fritzing/MPU-6050 Board GY-521.fzpz
2023-11-20 Rename Vibration sensor module.fzpz to Fritzing/Vibration sensor module.fzpz
2023-11-20 Update and rename basic_readings.ino to Arduino/basic_readings.ino
2023-12-11 Add files via upload
    Modo de funcionamiento: Prueba. Hay cosas definitivas y cosas experimentales.
